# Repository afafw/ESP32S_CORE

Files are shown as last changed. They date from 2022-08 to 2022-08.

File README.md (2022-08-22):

# ESP32S_CORE
一个超小廉价并且尽量保证可以手工焊接的esp32s之类的模块可用的开发板 尺寸2.7x4.88cm
小料基本上都是0603大小的0.1uf，10uf电容和0603 的10k电阻，同时esp32的焊盘选择了较宽的，基本保证有电烙铁就可以了（当然模块底下的地没链接性能不会很好）
bom成本（不包括模块）（不包括ch340c接口按键，模块）：大概1.3左右
加上ch340c，接口和按键也在3元附近。
至于esp32s模块 可以买全新的也可以选择闲鱼（笑）
通过各种手段压低成本（手焊，闲鱼等等）之后开发板成本可以在8元以下,弥补之前消失的9.9包邮开发板。
A cheap, small, hand solderable solution to use many expressif chip including esp32s2,esp32solo1,(any module with same design)

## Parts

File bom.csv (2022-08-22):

Designator | Footprint | Quantity | Value | LCSC Part #
U3 | HDR-TH_19P-P2.54-V-M | 1 | HDR_2.54-1x19P
C6 | C_0603_1608Metric | 1 | 10uf
IO12 | LED_0603_1608Metric | 1 | LED
R5 | R_0603_1608Metric | 1 | 10k
C5 | C_0603_1608Metric | 1 | 10uf
C1 | C_0603_1608Metric | 1 | 10uf
3V3 | LED_0603_1608Metric | 1 | LED
U1 | WIRELM-SMD_ESP32-S | 1 | ESP32-S
Q2 | SOT-23-3_L2.9-W1.3-P1.90-LS2.4-BR | 1 | SS8050_C2150
EN | SW-SMD_L4.0-W2.9-LS5.0 | 1 | TS-1088-AR02016
R2 | R_0603_1608Metric | 1 | 10k
C7 | C_0603_1608Metric | 1 | 10uf
IO0 | SW-SMD_L4.0-W2.9-LS5.0 | 1 | TS-1088-AR02016
C3 | C_0603_1608Metric | 1 | 10uf
U5 | SOP-16_L10.0-W3.9-P1.27-LS6.0-BL | 1 | CH340C
R4 | R_0603_1608Metric | 1 | 10k
R1 | R_0603_1608Metric | 1 | 10k
U2 | HDR-TH_19P-P2.54-V-M | 1 | HDR_2.54-1x19P
C4 | C_0603_1608Metric | 1 | 0.1uf
R3 | R_0603_1608Metric | 1 | 10k
C2 | C_0603_1608Metric | 1 | 0.1uf
USB1 | USB-C-SMD_KH-TYPE-C-16P | 1 | KH-TYPE-C-16P
U4 | SOT-223-3_L6.5-W3.4-P2.30-LS7.0-BR | 1 | AMS1117-3.3
Q1 | SOT-23-3_L2.9-W1.3-P1.90-LS2.4-BR | 1 | SS8050_C2150

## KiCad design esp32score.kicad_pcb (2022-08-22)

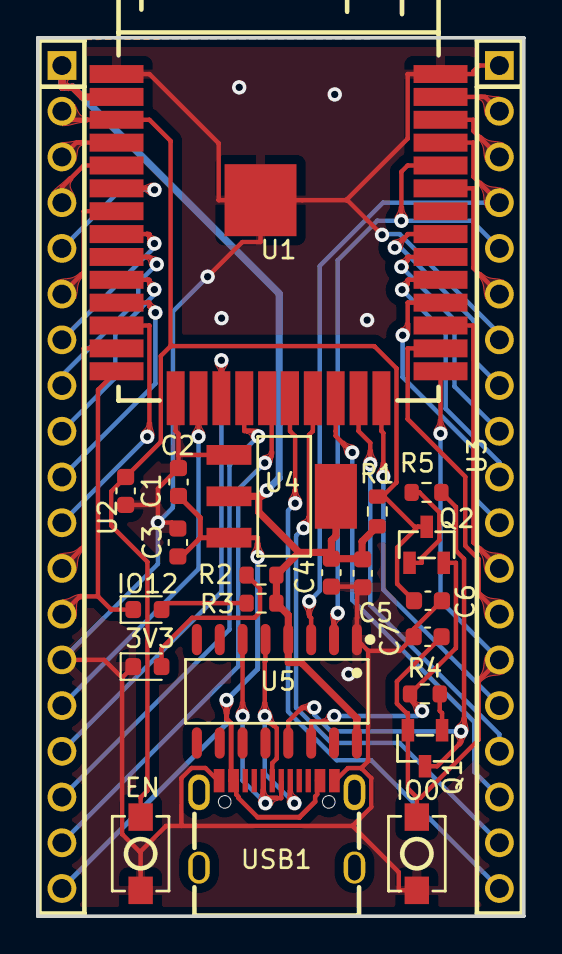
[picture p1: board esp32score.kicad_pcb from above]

Board: 2 copper layers, 27.0 x 48.8 mm, 24 parts (0 on the bottom side), 44 nets.

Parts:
3V3: LED; LED_0603_1608Metric
C1, C3, C5, C6, C7: 10uf; C_0603_1608Metric
C2, C4: 0.1uf; C_0603_1608Metric
EN: TS-1088-AR02016; SW-SMD_L4.0-W2.9-LS5.0
IO0: TS-1088-AR02016; SW-SMD_L4.0-W2.9-LS5.0
IO12: LED; LED_0603_1608Metric
Q1, Q2: SS8050_C2150; SOT-23-3_L2.9-W1.3-P1.90-LS2.4-BR
R1, R2, R3, R4, R5: 10k; R_0603_1608Metric
U1: ESP32-S; WIRELM-SMD_ESP32-S
U2, U3: HDR_2.54-1x19P; HDR-TH_19P-P2.54-V-M
U4: AMS1117-3.3; SOT-223-3_L6.5-W3.4-P2.30-LS7.0-BR
U5: CH340C; SOP-16_L10.0-W3.9-P1.27-LS6.0-BL
USB1: KH-TYPE-C-16P; USB-C-SMD_KH-TYPE-C-16P

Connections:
+3.3V: C4.1, C5.1, R1.1, R2.1, R3.1, U1.2 (3V3), U2.1, U4.2 (VOUT), U4.4 (VOUT), U5.4 (V3), U5.16 (VCC)
+5V: C2.1, C3.1, U2.19, U4.3 (VIN), USB1.A4 (VBUS), USB1.A9 (VBUS), USB1.B4 (VBUS), USB1.B9 (VBUS)
CLK: U1.20 (CLK), U3.19
CMD: U1.19 (CMD), U2.18
D+: U5.5 (D+), USB1.A6 (DP1), USB1.B6 (DP2)
D-: U5.6 (D-), USB1.A7 (DN1), USB1.B7 (DN2)
DTR: Q1.3 (C), R5.1, U5.13 (DTR#)
EN: C1.1, C6.1, EN.1, Q2.3 (C), R1.2, U1.3 (EN), U2.2
GND: 3V3.1 (K), C1.2, C2.2, C3.2, C4.2, C5.2, C6.2, C7.2, EN.2, IO0.2, U1.1 (GND), U1.15 (GND), U1.38 (GND), U1.39 (EP), U2.14, U3.1, U3.7, U4.1 (GND), U5.1 (GND), USB1.A1 (GND), USB1.A12 (GND), USB1.B1 (GND), USB1.B12 (GND)
GPIO2: U1.24 (IO2), U3.15
GPIO4: U1.26 (IO4), U3.13
GPIO5: U1.29 (IO5), U3.10
GPIO12: IO12.1 (K), U1.14 (IO12), U2.13
GPIO13: U1.16 (IO13), U2.15
GPIO14: U1.13 (IO14), U2.12
GPIO15: U1.23 (IO15), U3.16
GPIO16: U1.27 (IO16), U3.12
GPIO17: U1.28 (IO17), U3.11
GPIO18: U1.30 (IO18), U3.9
GPIO19: U1.31 (IO19), U3.8
GPIO21: U1.33 (IO21), U3.6
GPIO22: U1.36 (IO22), U3.3
GPIO23: U1.37 (IO23), U3.2
GPIO25: U1.10 (IO25), U2.9
GPIO26: U1.11 (IO26), U2.10
GPIO27: U1.12 (IO27), U2.11
GPIO32: U1.8 (IO32), U2.7
GPIO33: U1.9 (IO33), U2.8
GPIO34: U1.6 (IO34), U2.5
GPIO35: U1.7 (IO35), U2.6
IO0: C7.1, IO0.1, Q1.2 (E), U1.25 (IO0), U3.14
unnamed: 3V3.2 (A), R2.2
unnamed: IO12.2 (A), R3.2
unnamed: Q1.1 (B), R4.2
unnamed: Q2.1 (B), R5.2
RTS: Q2.2 (E), R4.1, U5.14 (RTS#)
RXD: U1.34 (U0RXD), U3.5, U5.2 (TXD)
SD0: U1.21 (SDO), U3.18
SD1: U1.22 (SDI), U3.17
SD2: U1.17 (SD2), U2.16
SD3: U1.18 (SD3), U2.17
SENSOR VN: U1.5 (SENSOR_VN), U2.4
SENSOR VP: U1.4 (SENSOR_VP), U2.3
TXD: U1.35 (U0TXD), U3.4, U5.3 (RXD)
